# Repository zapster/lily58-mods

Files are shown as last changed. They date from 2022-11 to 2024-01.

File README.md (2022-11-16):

# Lily58 Mods
Modifications and enhancements for the Lily58 keyboard.

This is currently work in progress.

## Firmware
QMK with the `zapster` keymap for the Lily58 keyboard: https://github.com/zapster/qmk_firmware

## USB C Interconnect

Replace the TRRS connection with an USB C receptacle to avoid short curcuits.
The idea is to create a PCB that can be soldered to the TRRS jacks footprint.
Since the USB C is non-standard and might be confused with the USB jacks on the MCU,
the interconnect will likely use a magnetic USB C cable.

Go to [Lily58_Pro_USB_C_Reset_Ext](./Lily58_Pro_USB_C_Reset_Ext/)

### Part Evaluation:
* USB C recaptacle: USB4110-GF-A
* Magnetic USB C cable: https://www.amazon.de/gp/product/B0B76D7L5Q/ref=ppx_yo_dt_b_asin_title_o01_s00?ie=UTF8&th=1
  * need to check number of wires and connectivity

## Palm Rest

Add a palm rest and potentially 3d print a case that supports it, also wrt. tenting.

### Parts

* first try: [Kensington K52802WW](https://www.kensington.com/p/products/ergonomic-desk-accessories/ergosoft-wrist-rest/kensington-ergosoft-wrist-rest-for-standard-mouse/)
  * not comfortable
* currently testing: non-name "Powcan Memory Foam" https://www.amazon.de/gp/product/B07JGDDCJM/ref=ppx_yo_dt_b_asin_title_o00_s00?ie=UTF8&psc=1
  * until now, rather nice

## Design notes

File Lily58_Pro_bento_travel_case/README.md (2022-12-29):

# Lily58 Bento Travel Box

## Revisions

### v0

#### Known Issues

* ~~~USB cutout not high enough (USB plug higher than PCB top).~~~
* ~~~Key head space not enough to hold USB and TRRS cables. Either increase or reduce to 15mm and store cables elsewhere.~~~
* 10% fill-in not enough at 0.3mm (bridging issues).
* Add ~~~version number~~~ and/or logo

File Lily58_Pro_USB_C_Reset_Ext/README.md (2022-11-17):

# Lily58 USB C Interconnect and Side-Reset Extension

Small extension board that adds an USB C jack for connecting the two keyboard sides
and a side-facing reset button.
The extension board is soldered onto the TRRS jack and reset button pads of the original Lily58 Pro PCB.

Similar to the main Lily58 board, the extension PCB is reversible,
so the same board can be used for the right and left side of the keyboard.

## Revision ExtUR0

The ExtUR0 revision of the PCB as been sent to the fab on 2022-11-15.

### Rendering

#### Front/Right Side
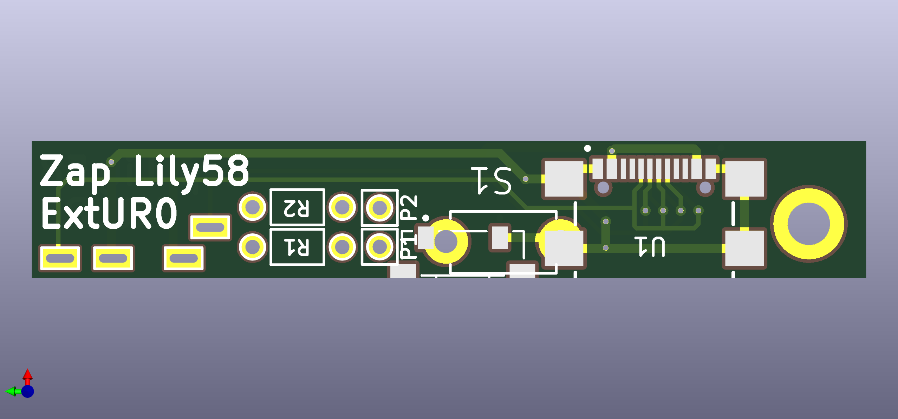
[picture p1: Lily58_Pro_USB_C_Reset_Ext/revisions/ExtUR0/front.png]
Front! Front aka Right Hand Side


#### Back/Left Side
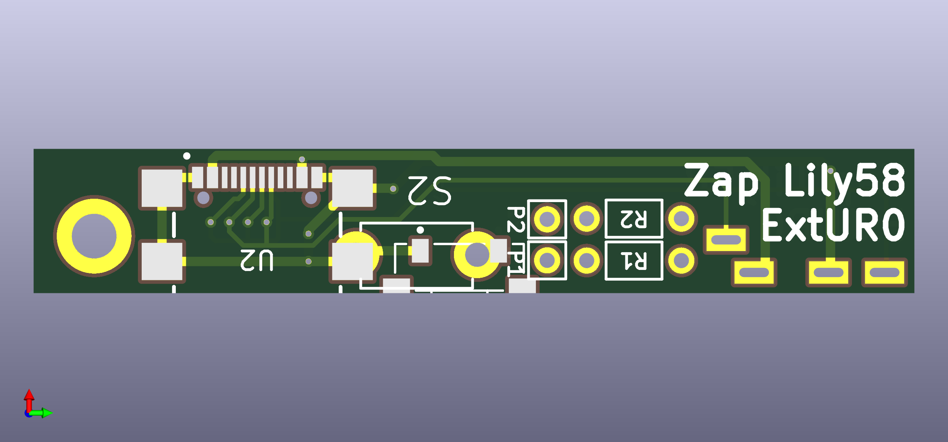
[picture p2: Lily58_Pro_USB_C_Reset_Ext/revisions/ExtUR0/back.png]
Back! Back aka Left Hand Side


### Holes

| Component | Hole | Pad |
| ---| ---- | --- |
| TRRS jack | 0.5mm x 1.6mm |1.2mm x 2.1mm|
| R1, R2, P1, P2 | 32mil (0.8128mm) | 55mil (1.3970mm) |
| Reset button | 1.3mm | 2.5mm |

### Bill of Material

For both keyboard sides.

| Qty | Part | Description | Comment |
| --- | --- | ---  | --- |
| 2 | TL3330AF130QG | Side-reset button | |
| 2 | USB4110-GF-A  | USB C receptacle  | |
| 8 | 3121-2-00-15-00-00-08-0 | Mill Max pin | TRRS |
| 4 | 3136-1-00-15-00-00-08-0 | Mill Max pin | Reset Button |

### Known Issues

* The part names and the board name silk screens are face the other direction. Since the parts are inherited from the Lily58 PCB, the board name should be flipped.
* All holes that connect to the Lily58 Pro PCB should probably use the same size for simplicity.

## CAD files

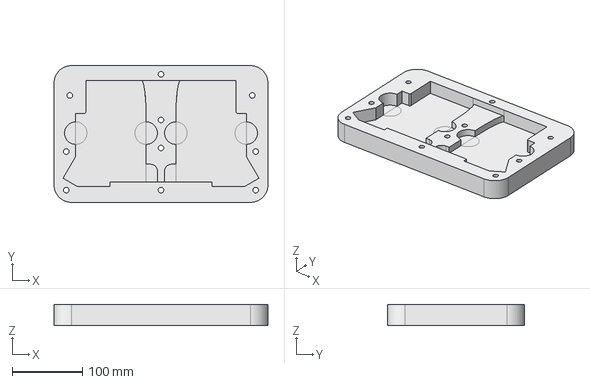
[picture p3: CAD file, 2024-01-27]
Lily58_extra_thumb_switch_mod/CaseInlay.FCStd
305.0 x 195.0 x 30.0 mm

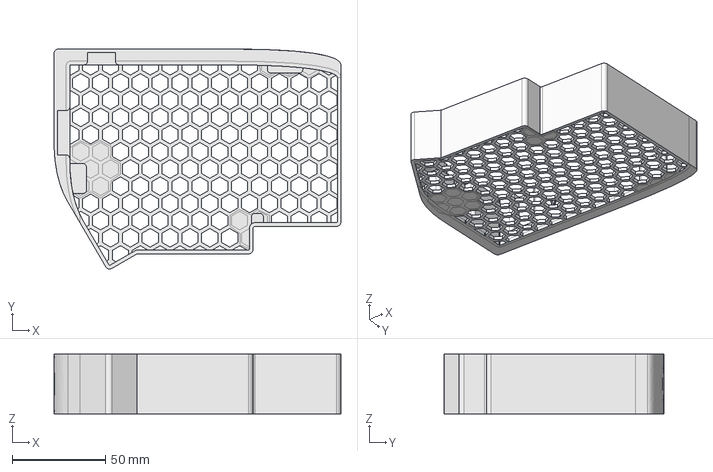
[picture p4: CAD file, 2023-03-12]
Lily58_Pro_bento_travel_case/BentoTravelCase.FCStd
154.0 x 118.1 x 32.0 mm

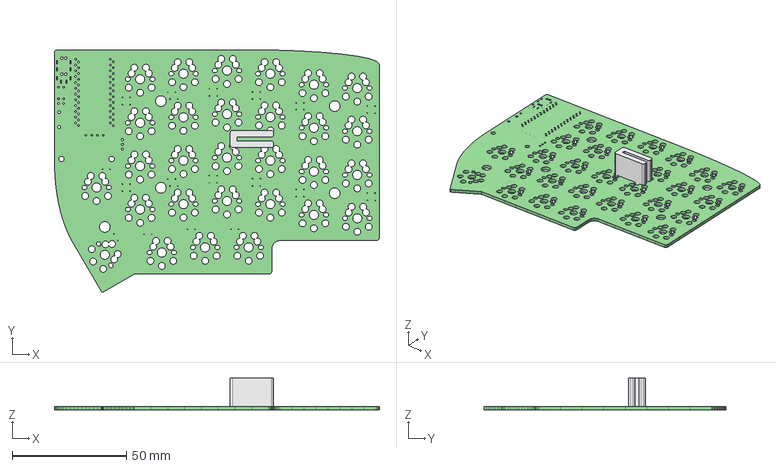
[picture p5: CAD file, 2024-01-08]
Lily58_extra_thumb_switch_mod/ExtraThumpSwitch.FCStd
142.5 x 106.3 x 14.0 mm
Clip
Lily58_Pro 1

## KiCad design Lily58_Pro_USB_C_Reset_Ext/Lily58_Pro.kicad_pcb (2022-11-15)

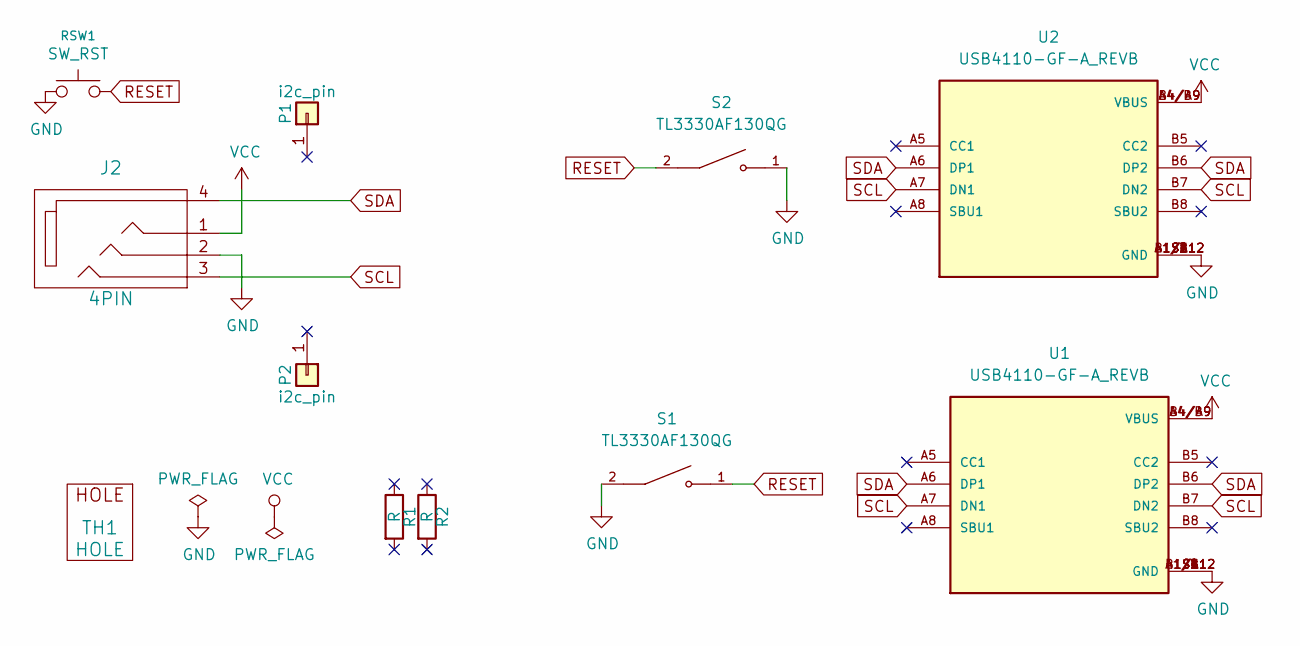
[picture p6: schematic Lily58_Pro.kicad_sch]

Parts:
J2: 4PIN; MJ-4PP-9
P1, P2: i2c_pin; 1pin_conn
R1, R2: R; RESISTOR_mini
RSW1: SW_RST; TACT_SWITCH_TVBP06
S1, S2: TL3330AF130QG; SW_TL3330AF130QG; PARTREV B
TH1: HOLE; M2_HOLE_PCB
U1, U2: USB4110-GF-A_REVB; GCT_USB4110-GF-A_REVB; PARTREV B

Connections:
GND: J2.2, RSW1.1, S1.2, S2.1, U1.A1/B12 (GND), U1.B1/A12 (GND), U1.S1 (GND), U1.S2 (GND), U1.S3 (GND), U1.S4 (GND), U2.A1/B12 (GND), U2.B1/A12 (GND), U2.S1 (GND), U2.S2 (GND), U2.S3 (GND), U2.S4 (GND)
RESET: RSW1.2, S1.1, S2.2
SCL: J2.3, U1.A7 (DN1), U1.B7 (DN2), U2.A7 (DN1), U2.B7 (DN2)
SDA: J2.4, U1.A6 (DP1), U1.B6 (DP2), U2.A6 (DP1), U2.B6 (DP2)
VCC: J2.1, U1.A4/B9 (VBUS), U1.B4/A9 (VBUS), U2.A4/B9 (VBUS), U2.B4/A9 (VBUS)

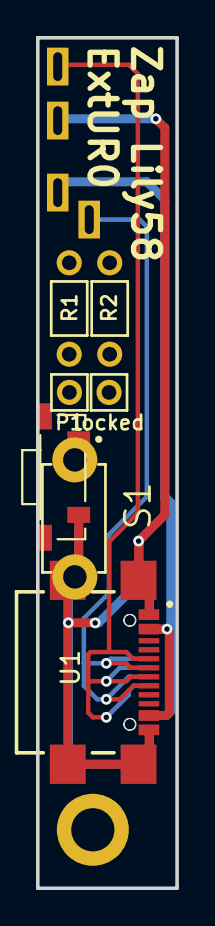
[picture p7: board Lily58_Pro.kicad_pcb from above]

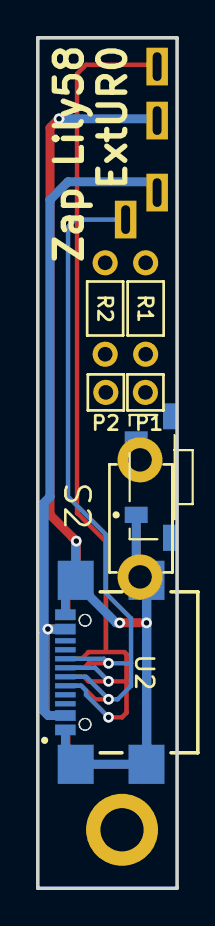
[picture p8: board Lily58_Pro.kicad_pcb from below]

Board: 2 copper layers, 7.7 x 47.2 mm, 11 parts (2 on the bottom side), 5 nets.

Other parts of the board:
locked: i2c_pin; 1pin_conn

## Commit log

2022-11-12 Lily58_mod_trrs: add initial back version
    [Lily58_mod_trrs-to-usb-c-back.kicad_pcb, Lily58_mod_trrs-to-usb-c-back.kicad_sch]
2022-11-12 Lily58_Pro_USB_C_Reset_Ext: drop Lily58 Pro files
    [Lily58_Pro.kicad_pcb, Lily58_Pro.sch]
2022-11-12 Lily58_Pro_USB_C_Reset_Ext: convert to new KiCad format
    [Lily58_Pro.kicad_pcb, Lily58_Pro.kicad_sch]
2022-11-12 Lily58_Pro_USB_C_Reset_Ext: remove old files
    [Lily58_Pro.sch]
2022-11-12 Lily58_Pro_USB_C_Reset_Ext: strip down
    [Lily58_Pro.kicad_pcb, Lily58_Pro.kicad_sch]
2022-11-12 Lily58_Pro_USB_C_Reset_Ext: add usb and reset
    [Lily58_Pro.kicad_pcb, Lily58_Pro.kicad_sch]
2022-11-13 Lily58_Pro_USB_C_Reset_Ext: change trrs jack and replace usb to metric
    [Lily58_Pro.kicad_pcb]
2022-11-14 Lily58_Pro_USB_C_Reset_Ext: routing
    [Lily58_Pro.kicad_pcb]
2022-11-14 Lily58_Pro_USB_C_Reset_Ext: better routing
    [Lily58_Pro.kicad_pcb]
2022-11-15 Lily58_Pro_USB_C_Reset_Ext: remove fill
    [Lily58_Pro.kicad_pcb, Lily58_Pro.kicad_sch]
2022-11-15 Lily58_Pro_USB_C_Reset_Ext: update via size
    [Lily58_Pro.kicad_pcb]
2022-11-16 Lily58_Pro_USB_C_Reset_Ext: add hole doc
2022-11-17 Lily58_Pro_USB_C_Reset_Ext: fix BOM quantities
2022-11-26 Lily58_Pro_case: initial
    [case.FCStd]
2022-11-29 Lily58_Pro_bento_travel_case: copy
    [case.FCStd]
2022-11-29 Lily58_Pro_bento_travel_case: add sketches and spreadsheet
    [BentoTravelCase.FCStd, case.FCStd]
2022-11-29 Lily58_Pro_bento_travel_case: extrude case
    [BentoTravelCase.FCStd]
2022-11-30 Lily58_Pro_bento_travel_case: base case ready
    [BentoTravelCase.FCStd]
2022-11-30 Lily58_Pro_bento_travel_case: right dimensions
    [BentoTravelCase.FCStd]
2022-11-30 Lily58_Pro_bento_travel_case: v1 draft
    [BentoTravelCase.FCStd]
2022-12-29 Lily58_Pro_bento_travel_case: deeper cut-out
    [BentoTravelCase.FCStd]
2022-12-29 Lily58_Pro_bento_travel_case: reduce keyspace to 15mm
    [BentoTravelCase.FCStd]
2022-12-29 Lily58_Pro_bento_travel_case: add version number
    [BentoTravelCase.FCStd]
2023-03-12 BentoTravelCase: left side
    [BentoTravelCase.FCStd]
2024-01-08 Lily58_extra_thumb_switch_mod: init
    [ExtraThumpSwitch.FCStd]
2024-01-08 Lily58_extra_thumb_switch_mod: bigger bottom
    [ExtraThumpSwitch.FCStd]
2024-01-08 Lily58_extra_thumb_switch_mod: v3
    [ExtraThumpSwitch.FCStd]
2024-01-10 Lily58_extra_thumb_switch_mod: case init
    [CaseInlay.FCStd]
2024-01-10 Lily58_extra_thumb_switch_mod: clean up
    [CaseInlay.FCStd]
2024-01-10 Lily58_extra_thumb_switch_mod: keyboard approximation
    [CaseInlay.FCStd]
2024-01-11 Lily58_extra_thumb_switch_mod: redraw
    [CaseInlay.FCStd]
2024-01-11 Lily58_extra_thumb_switch_mod: placement
    [CaseInlay.FCStd]
2024-01-11 Lily58_extra_thumb_switch_mod: rev1
    [CaseInlay.FCStd]
2024-01-27 CaseInlay: draw
    [CaseInlay.FCStd]
2024-01-27 CaseInlay: sections
    [CaseInlay.FCStd]
2025-05-06 Lily58_extra_thumb_switch_mod: case inlay svgs
